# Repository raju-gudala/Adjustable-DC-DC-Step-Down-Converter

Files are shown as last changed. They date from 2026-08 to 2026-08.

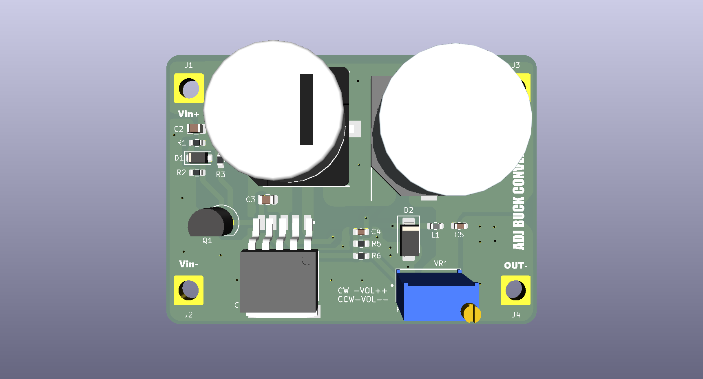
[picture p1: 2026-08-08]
Adjustable DC-DC buck converter.png

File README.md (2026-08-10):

# Adjustable DC-DC Step-Down Converter

This project demonstrates the design and implementation of an adjustable DC-DC buck converter using the **LM2596S-ADJ** IC. The converter accepts a wide input range of **4.5–40V DC** and delivers a regulated, adjustable output capable of supplying up to **3A** continuous current.

## Features

- Complete schematic design in KiCad
- LTspice simulation for stability and performance verification
- Optimized PCB layout for high efficiency and low output ripple
- Power stage, feedback network, and input/output filtering included
- Reliable voltage regulation using feedback compensation techniques

## Specifications

| Parameter | Value |
|---|---|
| IC | LM2596S-ADJ |
| Input Voltage | 5V – 40V DC |
| Output Voltage | Adjustable |
| Max Output Current | 3A (continuous) |
| Topology | Step-down (Buck) |

## Repository Contents

```
├── KiCad/          # Schematic and PCB layout files
├── LTspice/        # Simulation files for stability and performance analysis
└── README.md
```

## Design Overview

The converter is built around the LM2596S-ADJ switching regulator, configured with an external feedback resistor divider to allow adjustable output voltage. The design includes:

- **Power stage** — inductor, diode, and switching components sized for target load current
- **Feedback network** — resistor divider with compensation for stable regulation across the input range
- **Input/output filtering** — capacitor selection for ripple reduction and stability margin

## Simulation

LTspice simulations were used to verify loop stability and steady-state performance prior to PCB fabrication, validating transient response and output ripple against the design targets.

## PCB Layout

The PCB layout follows standard buck converter layout guidelines — minimized switching node area, tight power loop, and proper ground return paths — to reduce EMI and ripple while maximizing conversion efficiency.

## Tools Used

- **KiCad** — Schematic capture and PCB design
- **LTspice** — Circuit simulation and stability analysis

## License

Feel free to specify a license (e.g., MIT) if you'd like others to reuse this design.

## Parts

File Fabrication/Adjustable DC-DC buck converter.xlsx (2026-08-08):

S.No | Designator | MPN | Manufacturer | Description | Footprint | Qty | Link
1 | C1 | EEV-TG1H681UM | Panasonic | Aluminium Electrolytic Capacitors - SMD Al Lytic Cap125C SMT TG Series | CAPAE1700X1700N | 1 | https://mou.sr/3RBSC1R
2 | C2 | C0805Y104J5RACTU | KEMET | Multilayer Ceramic Capacitors MLCC - SMD/SMT 50V 0.1uF X7R 0805 5% Flex Soft | C_0805_2012Metric | 1 | https://mou.sr/4xsMxUn
3 | C3 | C0805X105J5RACAUTO | KEMET | Multilayer Ceramic Capacitors MLCC - SMD/SMT 50V 1uF 5% X7R 0805 AEC-Q200 | C_0805_2012Metric | 1 | https://mou.sr/4wNThMY
4 | C4 | C0603X471J5RACAUTO | KEMET | Multilayer Ceramic Capacitors MLCC - SMD/SMT 50V 470pF X7R 0603 5% Flex AEC-Q200 | C_0603_1608Metric |  | https://mou.sr/4hWnPas
5 | C5 | C0603C104J5RAC | KEMET | Multilayer Ceramic Capacitors MLCC - SMD/SMT 50V 0.1uF X7R 0603 5% | C_0603_1608Metric | 1 | https://mou.sr/4z4tUHZ
6 | C6 | UCZ1H471MNQ1MS | Nichicon | Aluminium Electrolytic Capacitors - SMD 50V 470UF 20% AEC-Q200 | CAPAE1710X1750N | 1 | https://mou.sr/4w8tCND
7 | IC1 | LM2596S-ADJ/NOPB | Texas Instruments | Switching Voltage Regulators 150 KHZ 3A STEP-DOWN VLTG REG A 926-LM25 A 926-LM2596SX-ADJNOPB | TO-263-5 | 1 | https://mou.sr/4xpxw5P
8 | VR1 | 3296W-1-103LF | Bourns | Trimmer Resistors - Through Hole 3/8" 10Kohms Sealed Vertical Adjust | 3296W1503LF | 1 | https://mou.sr/4waI1cd
9 | Q1 | 2N3904 | Diotec Semiconductor | Bipolar Transistors - BJT BJT, TO-92, 40V, 200mA, NPN | TO-92 | 1 | https://mou.sr/4wY9wXy
10 | D1 | BZT52C5V1 | Diotec Semiconductor | Zener Diodes Zener, SOD-123F, 5.1V, 0.5W, 5% | SOD-123F | 1 | https://mou.sr/3TIPKAY
11 | D2 | SS36 | Onsemi | Schottky Diodes & Rectifiers SHTKY DIODE 3A 60V | SMC (DO-214AB) | 1 | https://mou.sr/4fTiuy8
12 | R1, R2 | ERA-3VRW1002V | Panasonic | Thin Film Resistors - SMD 0603 0.05% 10Kohm 10ppm SMD | R_0603_1608Metric | 2 | https://mou.sr/4bBJRvm
13 | R3 | ERA-3VRW4702V | Panasonic | Thin Film Resistors - SMD 0603 0.05% 47Kohm 10ppm SMD | R_0603_1608Metric | 1 | https://mou.sr/3RU0Hiu
14 | R5 | ERA-3ARW102V | Panasonic | Thin Film Resistors - SMD 0603 1Kohm 0.05% 10ppm AEC-Q200 | R_0603_1608Metric | 1 | https://mou.sr/4wHmTeI
15 | R6 | ERA-3VEB1691V | Panasonic | Thin Film Resistors - SMD 0603 0.1% 1.69Kohm 25ppm SMD | R_0603_1608Metric | 1 | https://mou.sr/3SgPZme
16 | J1, J2, J3, J4 |  |  | Solder Wire Pads |  | 4

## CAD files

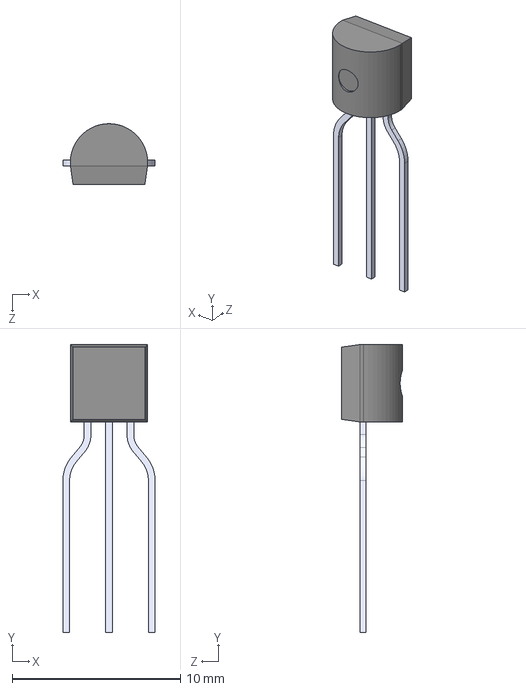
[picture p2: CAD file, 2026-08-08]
Components/2N3904/2N3904.stp
5.48 x 17.1 x 3.60 mm

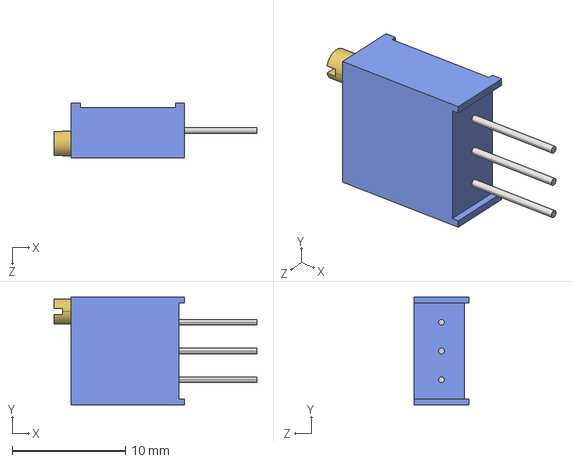
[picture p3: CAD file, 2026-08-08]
Components/3296W-1-103LF/3296W-1-103LF.stp
18.0 x 9.52 x 4.83 mm

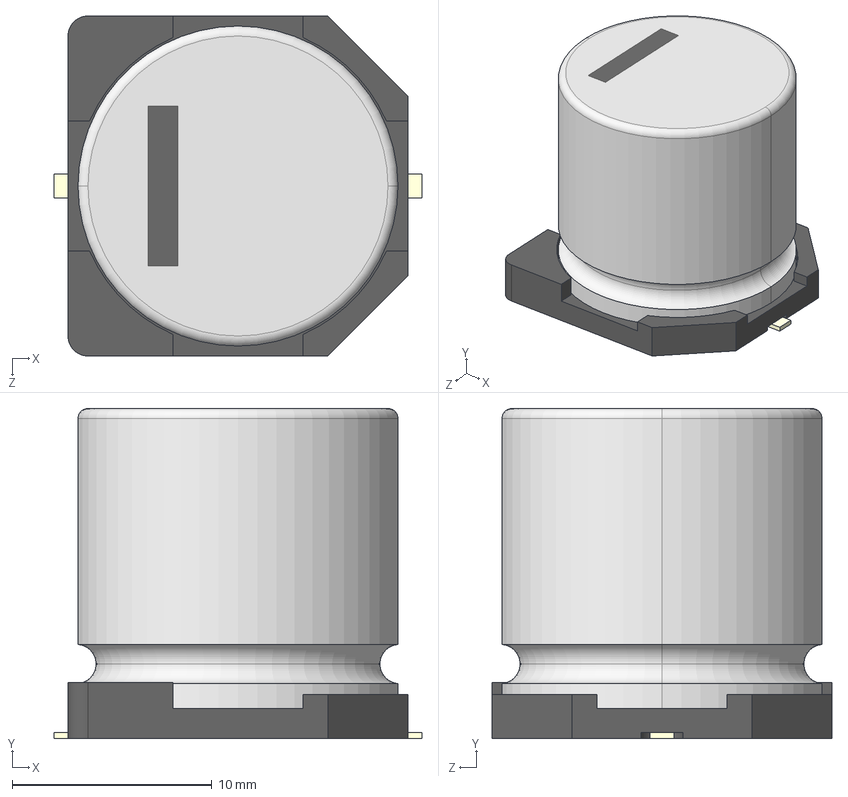
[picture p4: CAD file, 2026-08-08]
Components/EEE-FK1H471AM/EEE-FK1H471AM.stp
18.4 x 16.5 x 17.0 mm
標準SIZE CODE J16-001
標準SIZE CODE J16-002
標準SIZE CODE J16-003 x 2

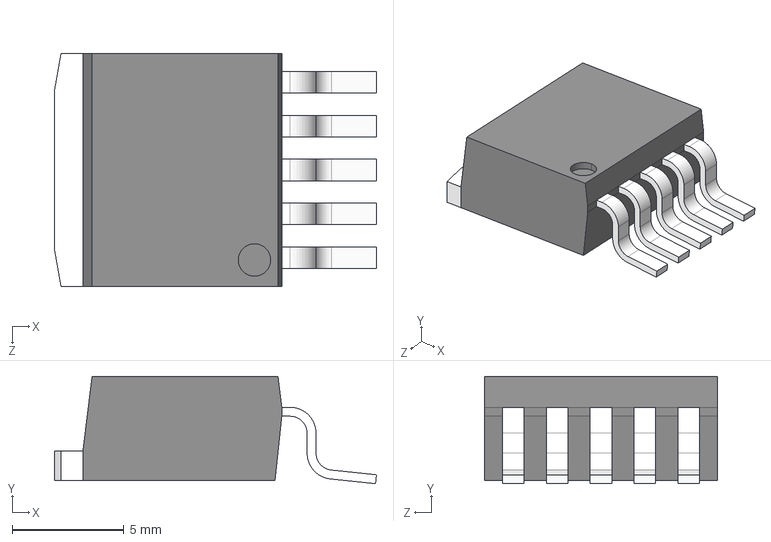
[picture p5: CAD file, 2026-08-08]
Components/LM2596S-ADJ_NOPB/LM2596S-ADJ_NOPB.stp
14.4 x 4.80 x 10.4 mm

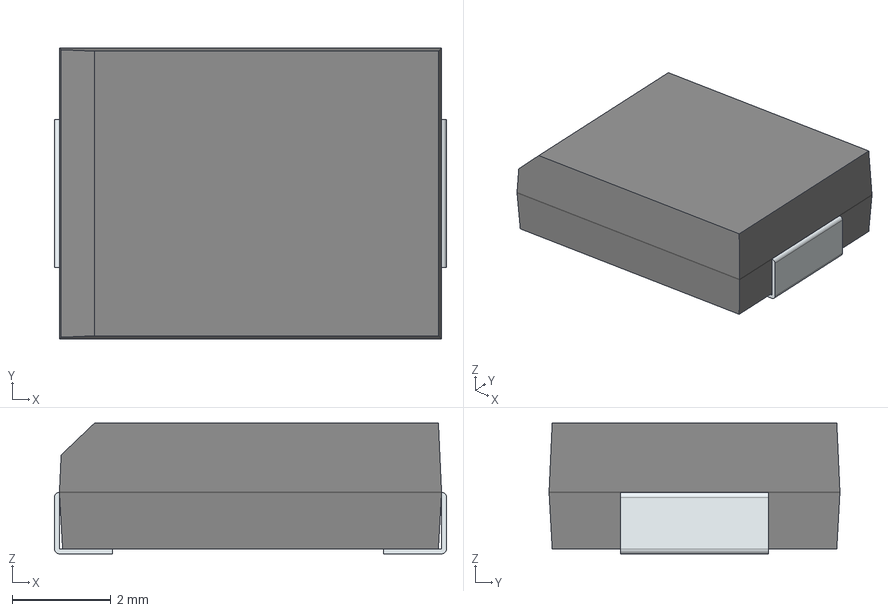
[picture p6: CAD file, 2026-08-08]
Components/SS36/SS36.stp
7.95 x 5.90 x 2.65 mm
FilletPin1
FilletPin2

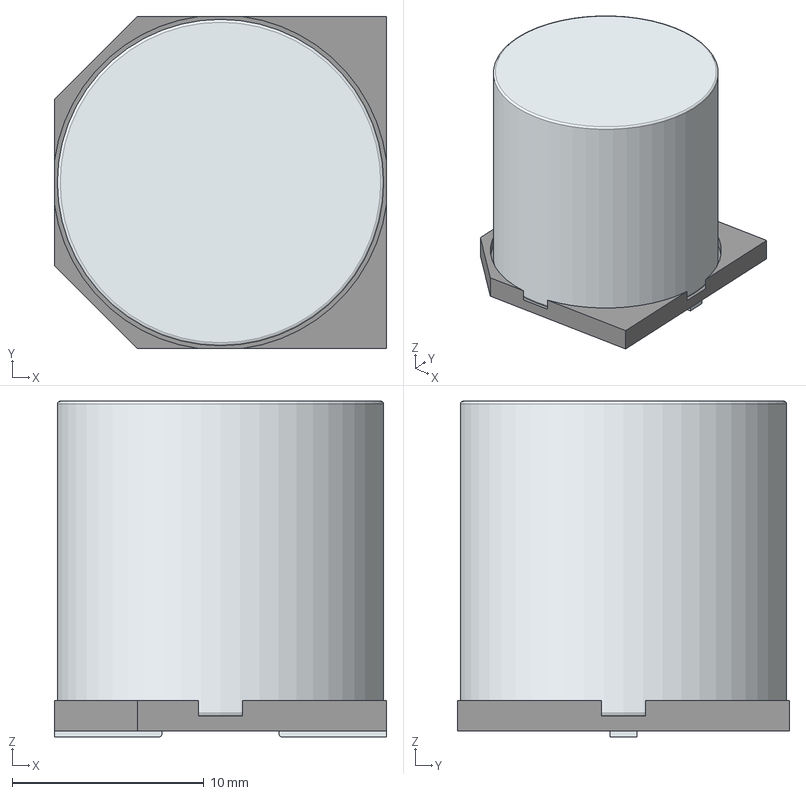
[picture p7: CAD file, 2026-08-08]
Components/UCZ1H471MNQ1MS/UCZ1H471MNQ1MS.stp
17.3 x 17.3 x 17.5 mm
Base
Pin1Fillet
Pin2Fillet

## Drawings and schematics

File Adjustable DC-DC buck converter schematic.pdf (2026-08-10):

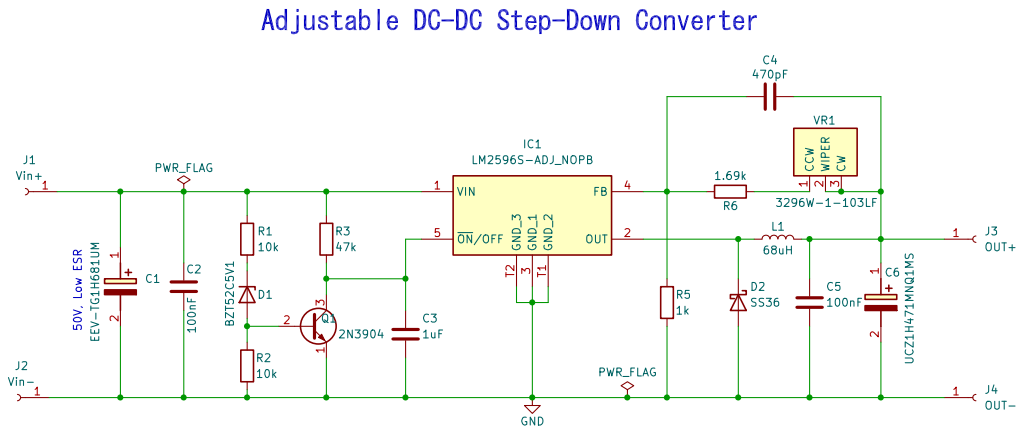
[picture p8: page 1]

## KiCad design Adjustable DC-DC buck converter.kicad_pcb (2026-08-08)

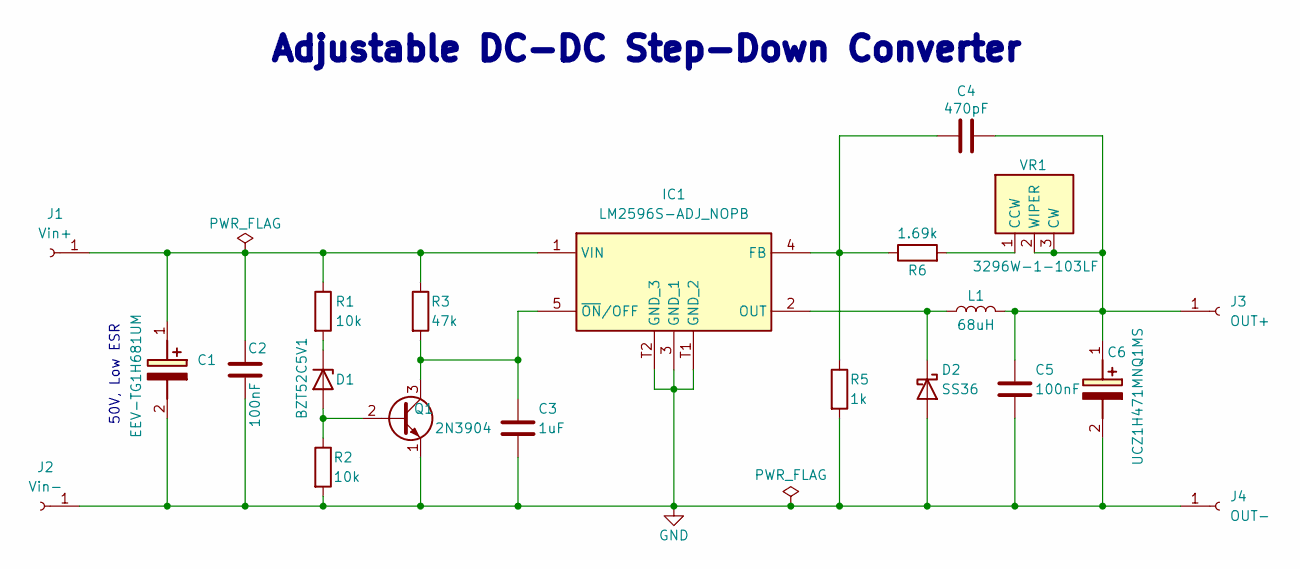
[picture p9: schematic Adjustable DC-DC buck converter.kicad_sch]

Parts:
C1: EEV-TG1H681UM; CAPAE1700X1700N; Mouser Part Number 667-EEV-TG1H681UM
C2: 100nF; C_0805_2012Metric
C3: 1uF; C_0805_2012Metric
C4: 470pF; C_0603_1608Metric
C5: 100nF; C_0603_1608Metric
C6: UCZ1H471MNQ1MS; CAPAE1710X1750N; Mouser Part Number 667-EEE-FK1H471AM
D1: BZT52C5V1; D_SOD-123F
D2: SS36; D_SMA
IC1: LM2596S-ADJ_NOPB; LM2596SXADJ; Mouser Part Number 926-LM2596S-ADJ/NOPB
J1: Vin+; SolderWire-2.5sqmm_1x01_D2.4mm_OD4.4mm
J2: Vin-; SolderWire-2.5sqmm_1x01_D2.4mm_OD4.4mm
J3: OUT+; SolderWire-2.5sqmm_1x01_D2.4mm_OD4.4mm
J4: OUT-; SolderWire-2.5sqmm_1x01_D2.4mm_OD4.4mm
L1: 68uH; L_0603_1608Metric
Q1: 2N3904; TO-92_Inline
R1, R2: 10k; R_0603_1608Metric
R3: 47k; R_0603_1608Metric
R5: 1k; R_0603_1608Metric
R6: 1.69k; R_0603_1608Metric
VR1: 3296W-1-103LF; 3296W1503LF; Mouser Part Number 652-3296W-1-103LF

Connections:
GND: C1.2 (-), C2.2, C3.2, C5.2, C6.2 (-), D2.2 (A), IC1.3 (GND_1), IC1.T1 (GND_2), IC1.T2 (GND_3), J2.1 (Pin_1_1), J4.1 (Pin_1_1), Q1.1 (E), R2.2, R5.2
unnamed: C1.1 (+), C2.1, IC1.1 (VIN), J1.1 (Pin_1_1), R1.1, R3.1
unnamed: C4.2, C5.1, C6.1 (+), J3.1 (Pin_1_1), L1.2, VR1.2 (WIPER), VR1.3 (CW)
unnamed: D1.2 (A), Q1.2 (B), R2.1
unnamed: D1.1 (K), R1.2
unnamed: D2.1 (K), IC1.2 (OUT), L1.1
unnamed: C4.1, IC1.4 (FB), R5.1, R6.1
unnamed: C3.1, IC1.5 (~ON/OFF), Q1.3 (C), R3.2
unnamed: R6.2, VR1.1 (CCW)

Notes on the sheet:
50V, Low ESR
Adjustable DC-DC Step-Down Converter

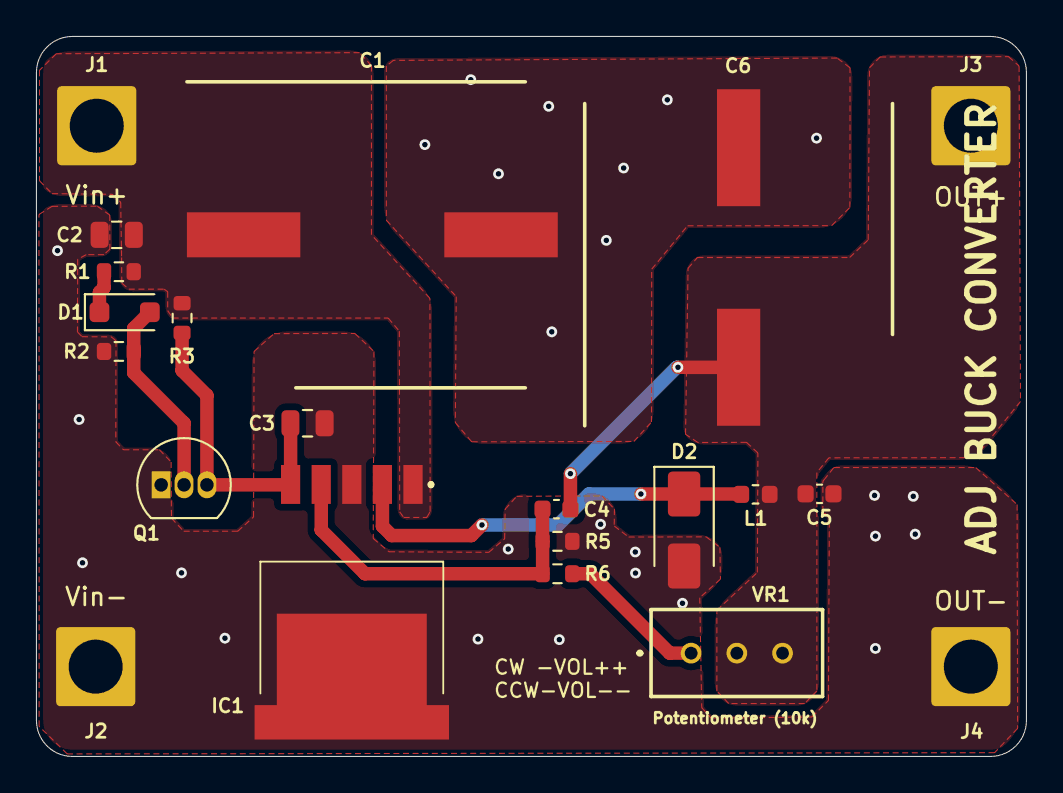
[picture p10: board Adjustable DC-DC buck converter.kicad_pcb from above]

Board: 2 copper layers, 55.0 x 40.0 mm, 21 parts (0 on the bottom side), 9 nets.
